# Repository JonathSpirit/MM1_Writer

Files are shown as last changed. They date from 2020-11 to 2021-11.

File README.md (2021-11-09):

# MM1_Writer

Copyright (C) 2021 Guillaume Guillet\
Licensed under CERN-OHL-W v2 or later

<table border="0px">
<tr>
<td>
This source describes Open Hardware and is licensed under the CERN-OHL-W v2 or later.
</td>
</tr>
<tr>
<td>
You may redistribute and modify this documentation and make products
using it under the terms of the CERN-OHL-W v2 (https:/cern.ch/cern-ohl).
This documentation is distributed WITHOUT ANY EXPRESS OR IMPLIED
WARRANTY, INCLUDING OF MERCHANTABILITY, SATISFACTORY QUALITY
AND FITNESS FOR A PARTICULAR PURPOSE. Please see the CERN-OHL-W v2
for applicable conditions.
</td>
</tr>
</table>

Made with [Kicad](https://kicad.org/)

## Description
This is a board helper for programming memory module that follow [MM1 standard](https://github.com/JonathSpirit/GComputer_standard).\
You can find the uc code here : [MM1_Writer_code](https://github.com/JonathSpirit/MM1_Writer_code).

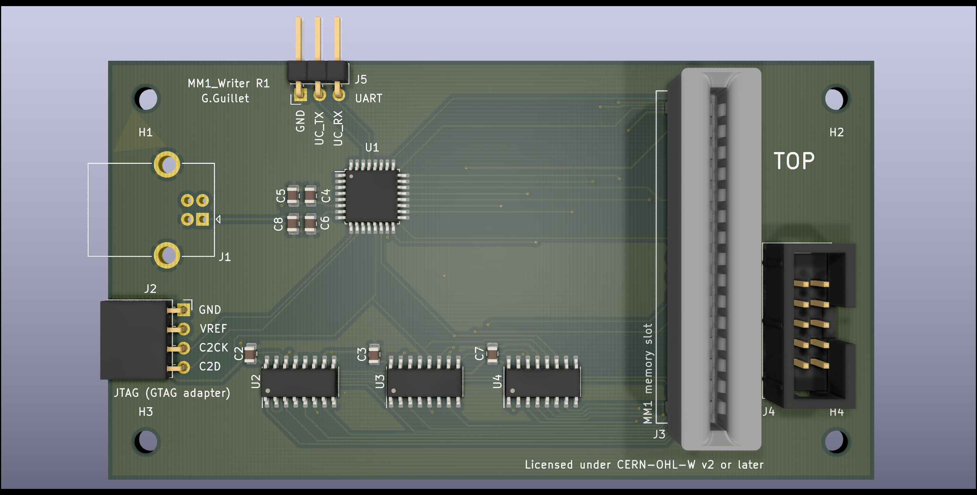
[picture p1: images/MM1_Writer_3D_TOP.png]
MM1_Writer_3D_TOP_image
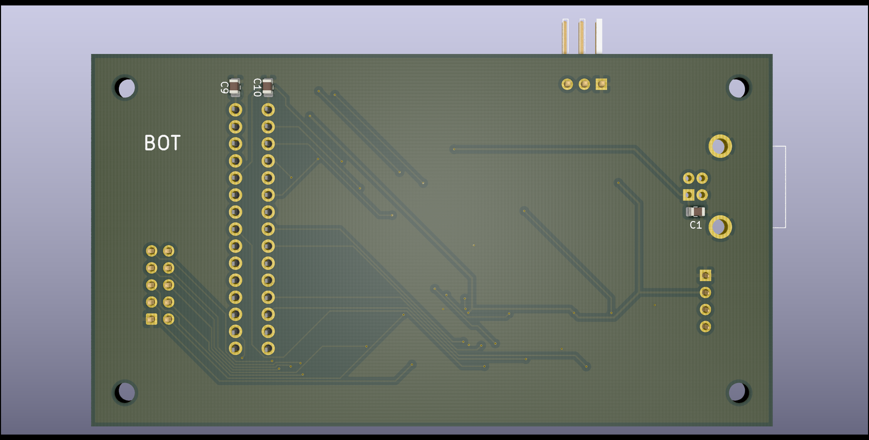
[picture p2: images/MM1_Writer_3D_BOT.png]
MM1_Writer_3D_BOT_image
 

## Stats





\
\
\


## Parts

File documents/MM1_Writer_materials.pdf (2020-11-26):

1

MM1_Writer_materials.fods

| MM1_Writer | R1
Author : Guillaume Guillet | Revision 1 | Licensed under CERN-OHL-W v2 or later
Type | Value | Q | References | Package | Manufacturer | Store | Store ID | Unit price* | Price
C | 10nF | 3 | C2, C3, C7 | C_0805_2012Metric | KEMET | Mouser | 80-C0805C103J5R | 0.092 | 0.276
| 1uF | 2 | C4, C6 | C_0805_2012Metric | KEMET | Mouser | 80-C0805C105K4RAC | 0.092 | 0.184
| 100nF | 5 | C1, C5, C8 to C10 | C_0805_2012Metric | KEMET | Mouser | 80-C0805C104M3R | 0.092 | 0.46
U | C8051F385-GQ | 1 | U1 | LQFP-32_7x7mm_P0.8mm | Silicon Labs | Mouser | 634-C8051F385-GQ | 2.52 | 2.52
| 74AHC595 | 3 | U2 to U4 | SOIC-16_3.9x9.9mm_P1.27mm | Texas Instruments | Mouser | 595-SN74AHC595DR | 0.485 | 1.455
J | Header10p | 1 | J4 | Header_10p_2.54 | Wurth Electronics | Mouser | 710-61201021621 | 0.411 | 0.411
| 5530843-2 | 1 | J3 | TE_5530843-2 | TE connectivity | Mouser | 571-5530843-2 | 2.33 | 2.33
| USB_B | 1 | J1 | USB_B_OST_USB-B1HSxx_Horizontal | Amphenol FCI | Mouser | 649-61729-0010BLF | 0.896 | 0.896
| PinSocket_1x04 | 1 | J2 | PinSocket_1x04_P2.54mm_Horizontal | Preci-dip | Mouser | 437-8018700420001101 | 0.585 | 0.585
| PinHeader_1x03 | 1 | J5 | PinHeader_1x03_P2.54mm_Horizontal | Molex | Mouser | 538-22-28-8033 | 0.247 | 0.247
- | PCB | 1 | - | - | G.Guillet | - | | | 0
Total price : | 9.364
*Depend of the quantity | Price is in CHF

# Project :

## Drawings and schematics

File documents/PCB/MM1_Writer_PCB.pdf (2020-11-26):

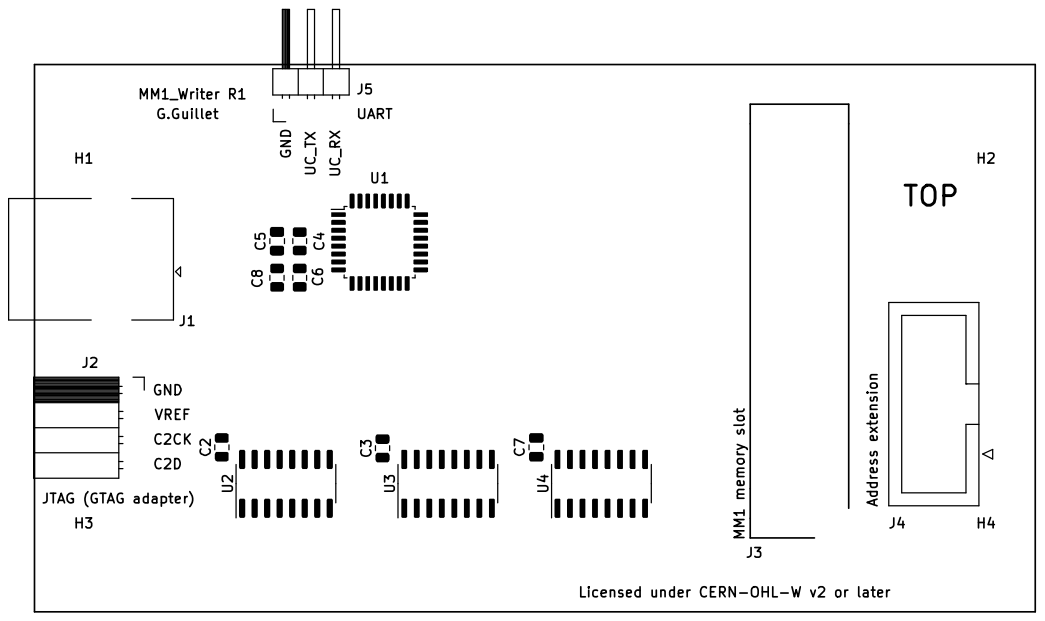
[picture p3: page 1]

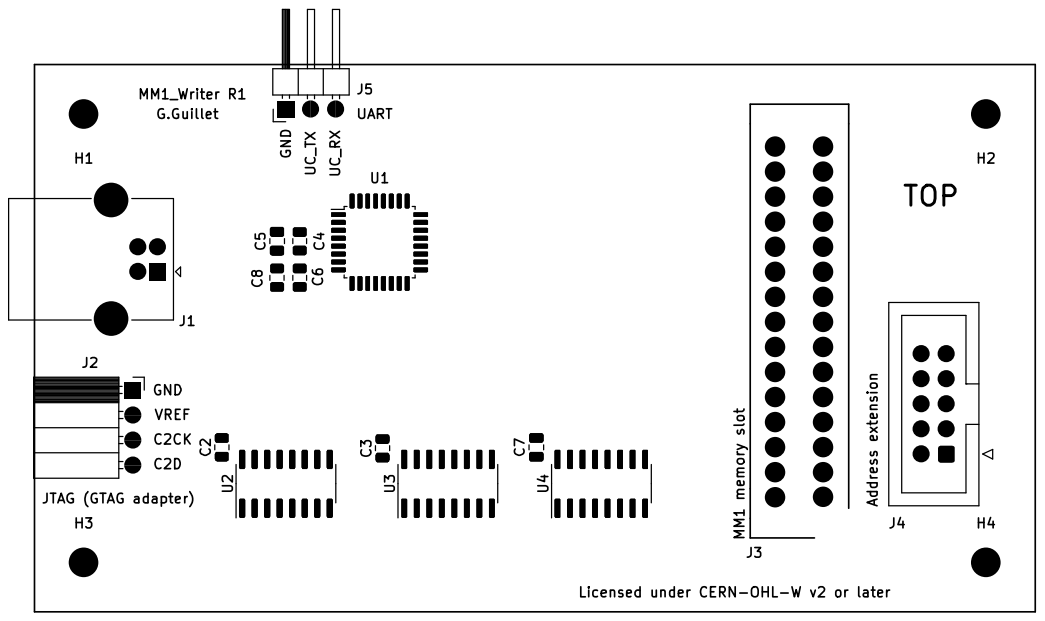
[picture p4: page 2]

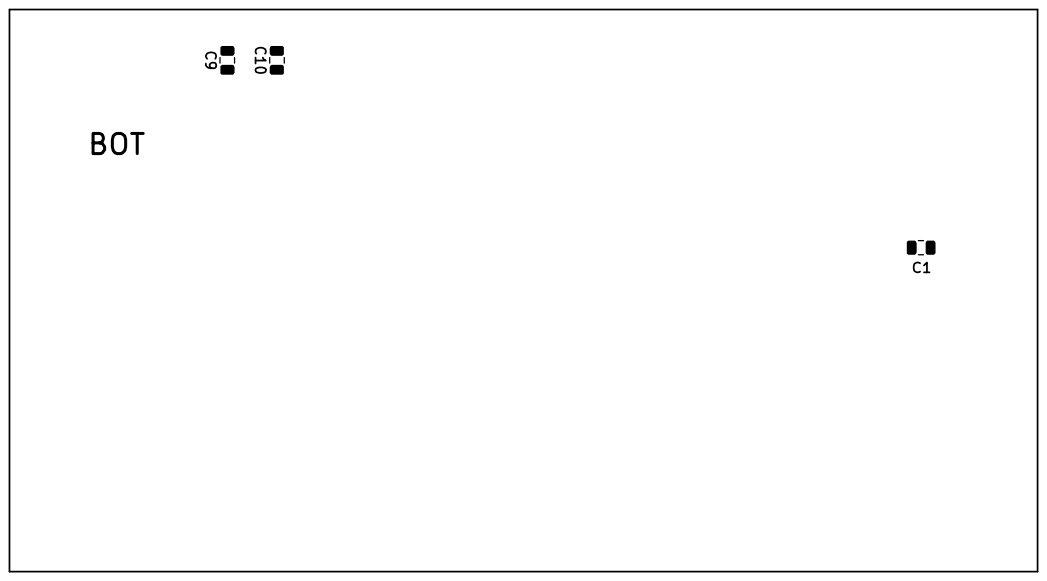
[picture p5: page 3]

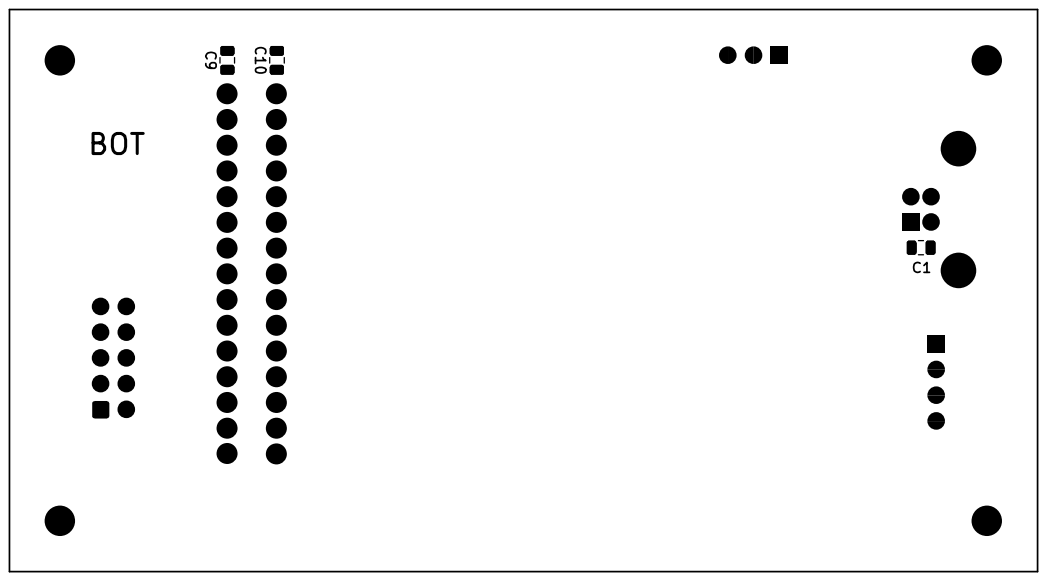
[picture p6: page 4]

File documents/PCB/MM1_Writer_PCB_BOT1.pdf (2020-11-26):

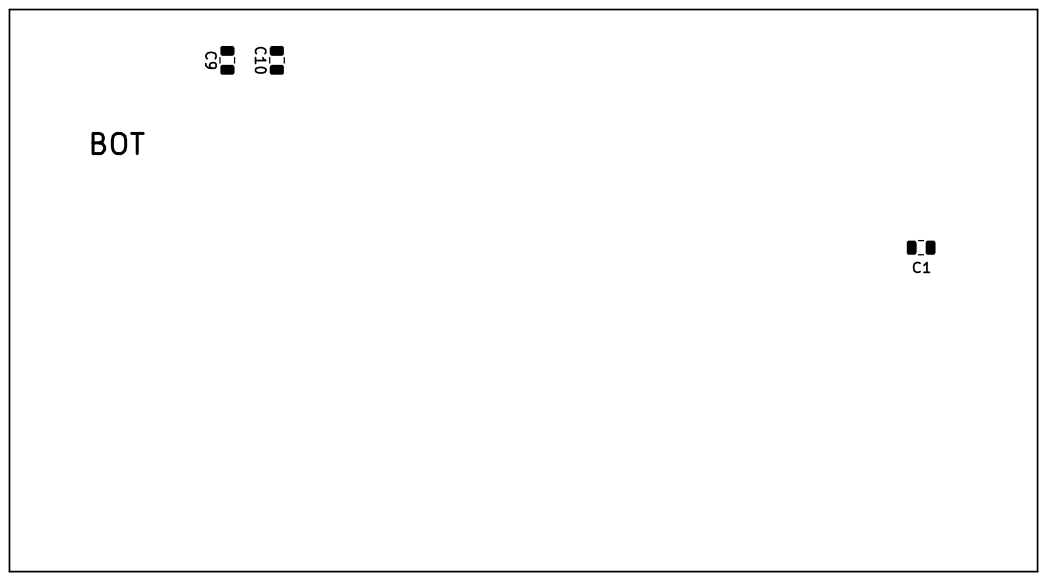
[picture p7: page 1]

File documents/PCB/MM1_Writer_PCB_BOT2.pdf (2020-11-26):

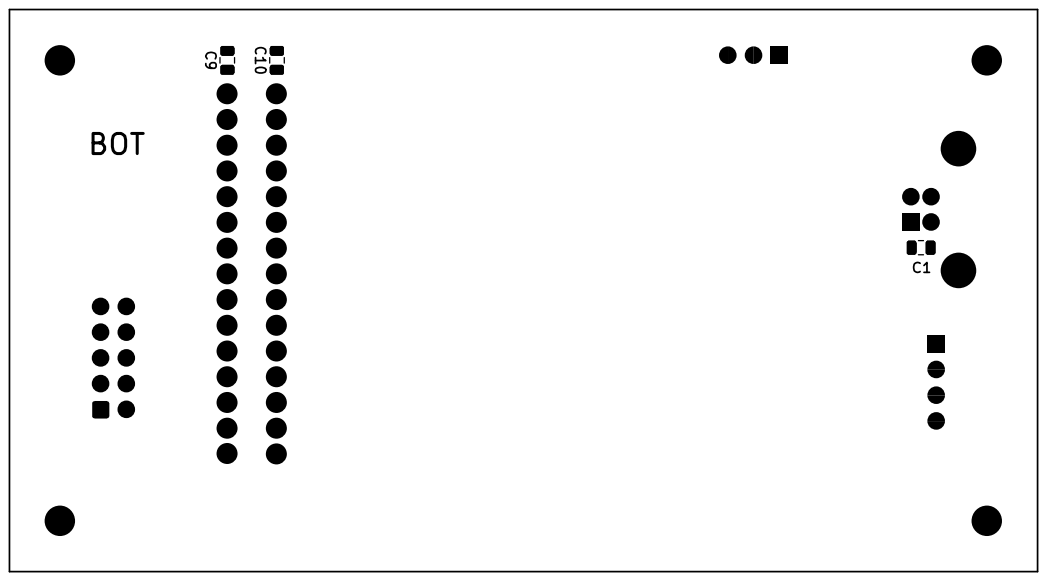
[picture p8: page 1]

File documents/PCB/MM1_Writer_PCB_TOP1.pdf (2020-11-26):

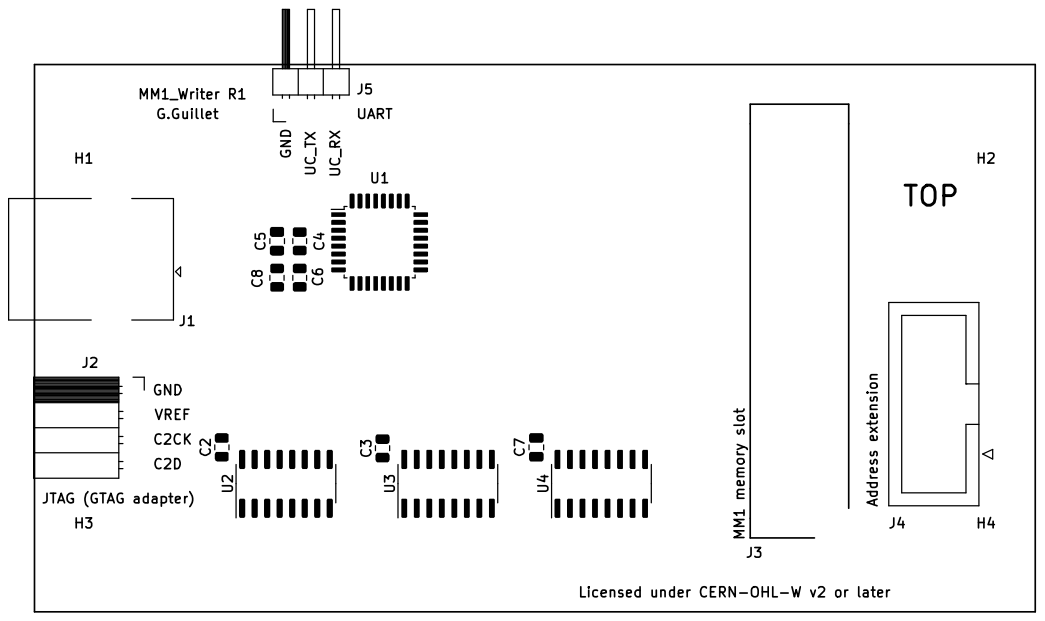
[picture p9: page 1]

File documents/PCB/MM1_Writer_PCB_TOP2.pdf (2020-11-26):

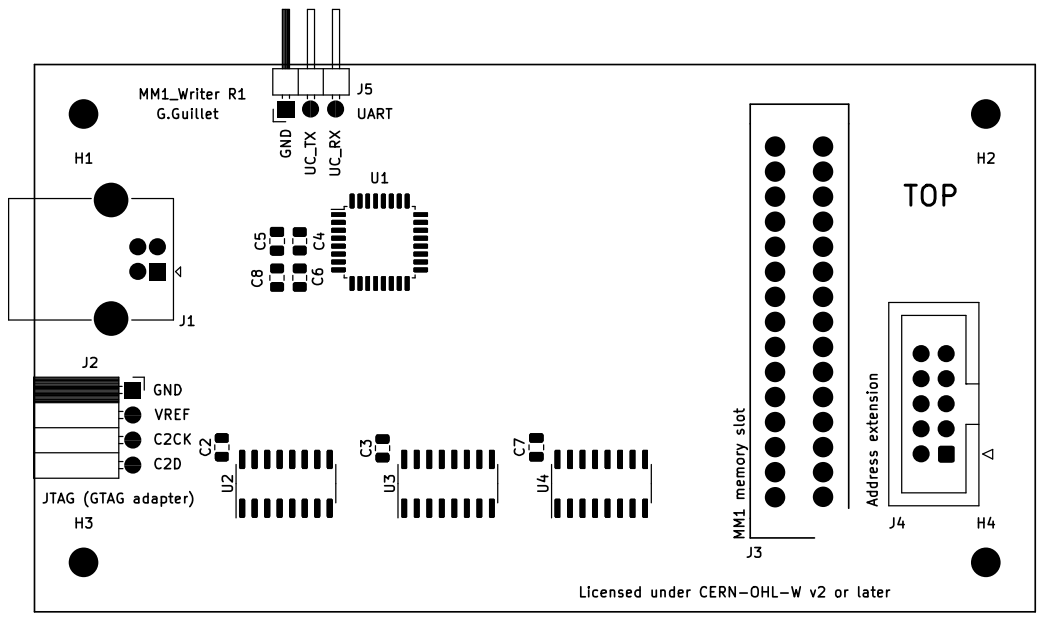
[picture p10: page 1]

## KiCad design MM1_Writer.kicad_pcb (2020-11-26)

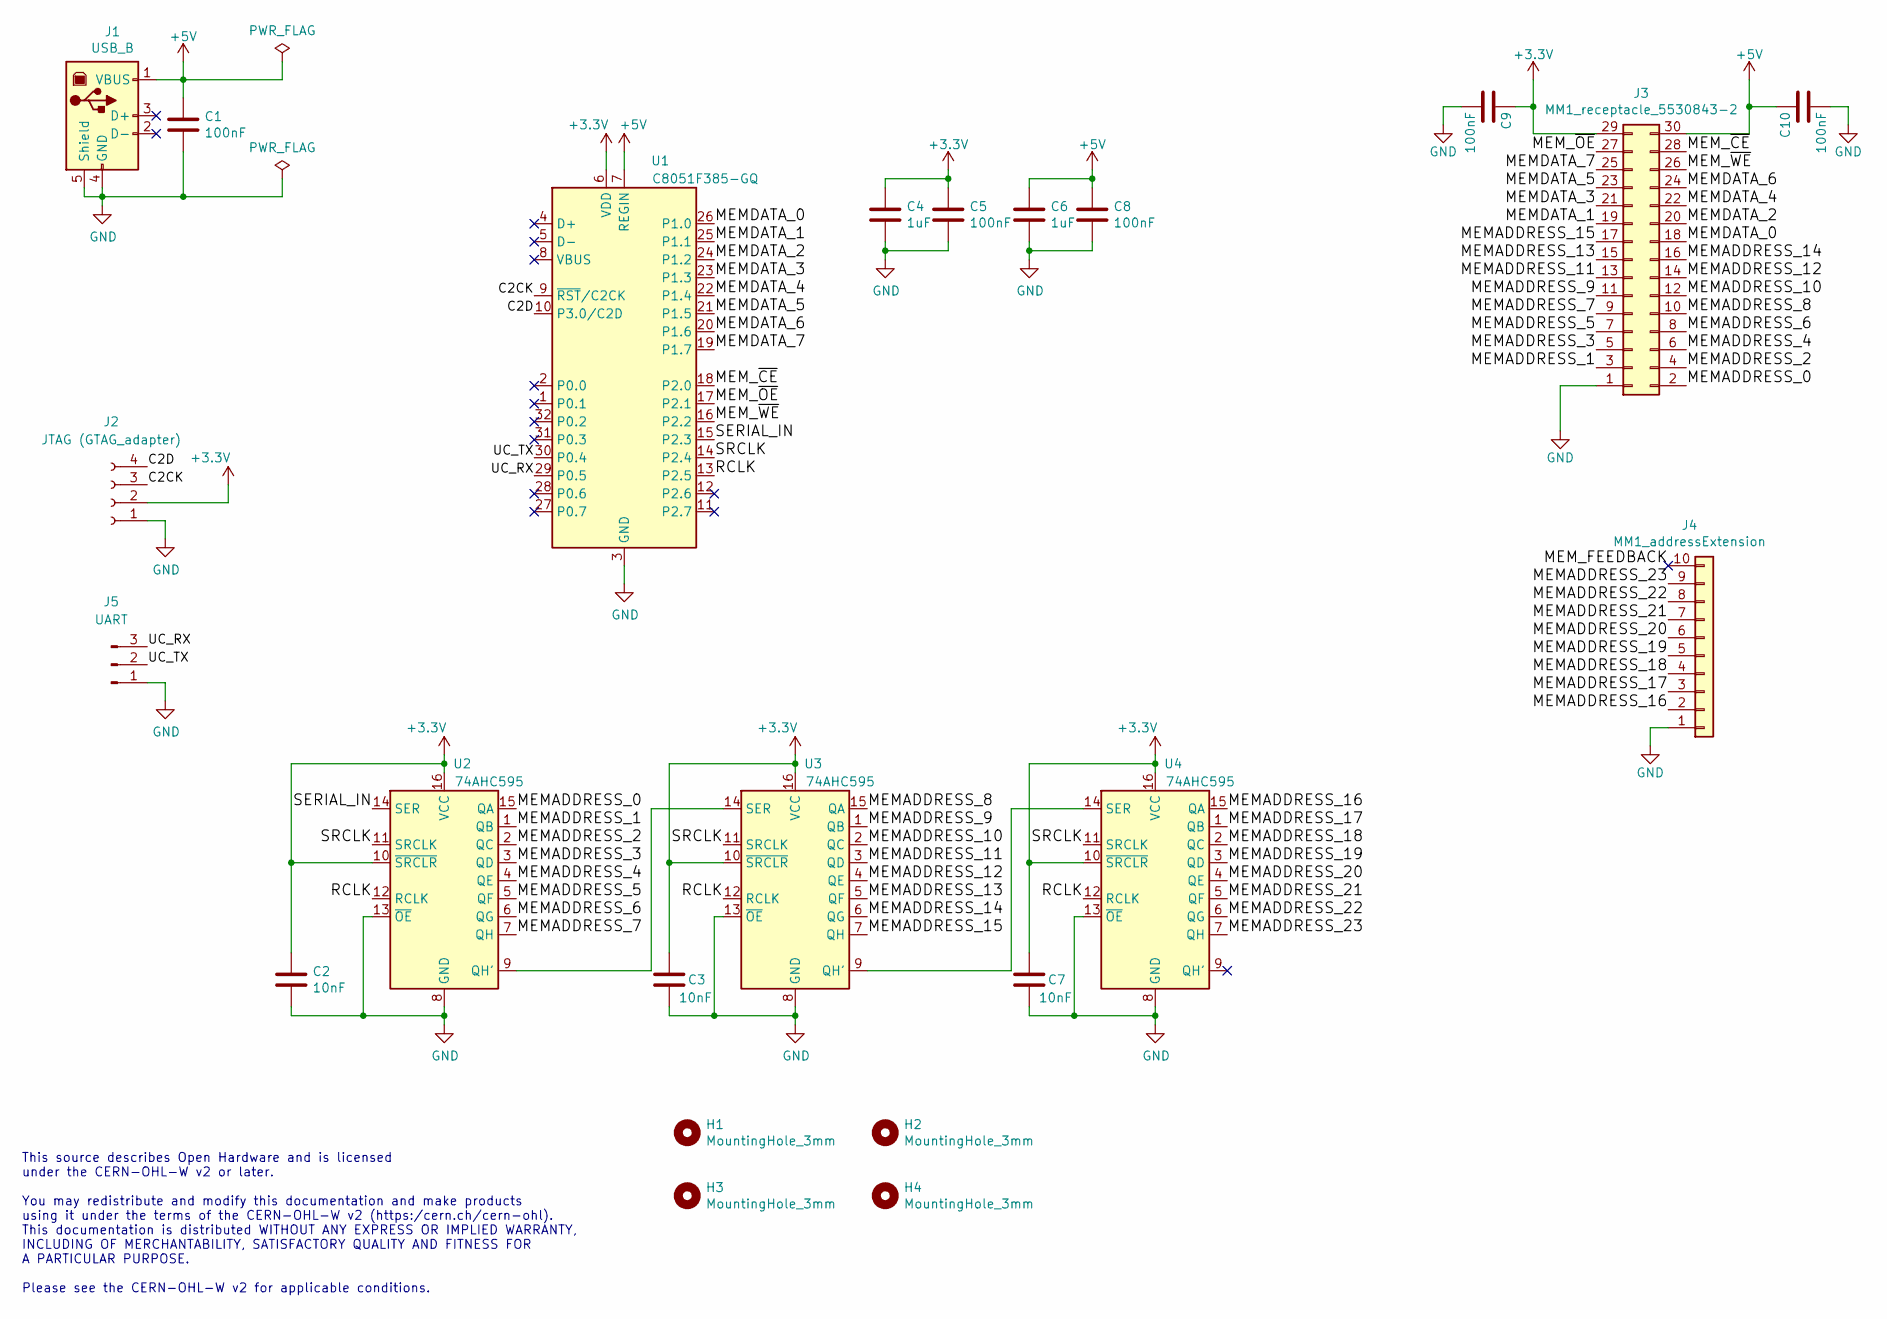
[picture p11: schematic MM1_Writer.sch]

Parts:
C1, C5, C8, C9, C10: 100nF; C_0805_2012Metric
C2, C3, C7: 10nF; C_0805_2012Metric
C4, C6: 1uF; C_0805_2012Metric
H1, H2, H3, H4: MountingHole_3mm
J1: USB_B; USB_B_OST_USB-B1HSxx_Horizontal
J2: JTAG (GTAG_adapter); PinSocket_1x04_P2.54mm_Horizontal
J3: MM1_receptacle_5530843-2; TE_5530843-2
J4: MM1_addressExtension; IDC-Header_2x05_P2.54mm_Vertical
J5: UART; PinHeader_1x03_P2.54mm_Horizontal
U1: C8051F385-GQ; LQFP-32_7x7mm_P0.8mm
U2, U3, U4: 74AHC595; SOIC-16_3.9x9.9mm_P1.27mm

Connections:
+3V3: C2.1, C3.1, C4.1, C5.1, C7.1, C9.1, J2.2, J3.29, U1.6 (VDD), U2.10 (~SRCLR), U2.16 (VCC), U3.10 (~SRCLR), U3.16 (VCC), U4.10 (~SRCLR), U4.16 (VCC)
+5V: C1.1, C6.1, C8.1, C10.1, J1.1 (VBUS), J3.30, U1.7 (REGIN)
/C2CK: J2.3, U1.9 (~RST~/C2CK)
/C2D: J2.4, U1.10 (P3.0/C2D)
/MEMADDRESS_0: J3.2, U2.15 (QA)
/MEMADDRESS_1: J3.3, U2.1 (QB)
/MEMADDRESS_2: J3.4, U2.2 (QC)
/MEMADDRESS_3: J3.5, U2.3 (QD)
/MEMADDRESS_4: J3.6, U2.4 (QE)
/MEMADDRESS_5: J3.7, U2.5 (QF)
/MEMADDRESS_6: J3.8, U2.6 (QG)
/MEMADDRESS_7: J3.9, U2.7 (QH)
/MEMADDRESS_8: J3.10, U3.15 (QA)
/MEMADDRESS_9: J3.11, U3.1 (QB)
/MEMADDRESS_10: J3.12, U3.2 (QC)
/MEMADDRESS_11: J3.13, U3.3 (QD)
/MEMADDRESS_12: J3.14, U3.4 (QE)
/MEMADDRESS_13: J3.15, U3.5 (QF)
/MEMADDRESS_14: J3.16, U3.6 (QG)
/MEMADDRESS_15: J3.17, U3.7 (QH)
/MEMADDRESS_16: J4.2, U4.15 (QA)
/MEMADDRESS_17: J4.3, U4.1 (QB)
/MEMADDRESS_18: J4.4, U4.2 (QC)
/MEMADDRESS_19: J4.5, U4.3 (QD)
/MEMADDRESS_20: J4.6, U4.4 (QE)
/MEMADDRESS_21: J4.7, U4.5 (QF)
/MEMADDRESS_22: J4.8, U4.6 (QG)
/MEMADDRESS_23: J4.9, U4.7 (QH)
/MEMDATA_0: J3.18, U1.26 (P1.0)
/MEMDATA_1: J3.19, U1.25 (P1.1)
/MEMDATA_2: J3.20, U1.24 (P1.2)
/MEMDATA_3: J3.21, U1.23 (P1.3)
/MEMDATA_4: J3.22, U1.22 (P1.4)
/MEMDATA_5: J3.23, U1.21 (P1.5)
/MEMDATA_6: J3.24, U1.20 (P1.6)
/MEMDATA_7: J3.25, U1.19 (P1.7)
/MEM_FEEDBACK: J4.10
/MEM_~CE: J3.28, U1.18 (P2.0)
/MEM_~OE: J3.27, U1.17 (P2.1)
/MEM_~WE: J3.26, U1.16 (P2.2)
/RCLK: U1.13 (P2.5), U2.12 (RCLK), U3.12 (RCLK), U4.12 (RCLK)
/SERIAL_IN: U1.15 (P2.3), U2.14 (SER)
/SRCLK: U1.14 (P2.4), U2.11 (SRCLK), U3.11 (SRCLK), U4.11 (SRCLK)
/UC_RX: J5.3, U1.29 (P0.5)
/UC_TX: J5.2, U1.30 (P0.4)
GND: C1.2, C2.2, C3.2, C4.2, C5.2, C6.2, C7.2, C8.2, C9.2, C10.2, J1.4 (GND), J1.5 (Shield), J2.1, J3.1, J4.1, J5.1, U1.3 (GND), U2.8 (GND), U2.13 (~OE), U3.8 (GND), U3.13 (~OE), U4.8 (GND), U4.13 (~OE)
unnamed: U2.9 (QH'), U3.14 (SER)
unnamed: U3.9 (QH'), U4.14 (SER)

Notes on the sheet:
This source describes Open Hardware and is licensed under the CERN-OHL-W v2 or later. You may redistribute and modify this documentation and make products using it under the terms of the CERN-OHL-W v2 (https:/cern.ch/cern-ohl). This documentation is distributed WITHOUT ANY EXPRESS OR IMPLIED WARRAN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

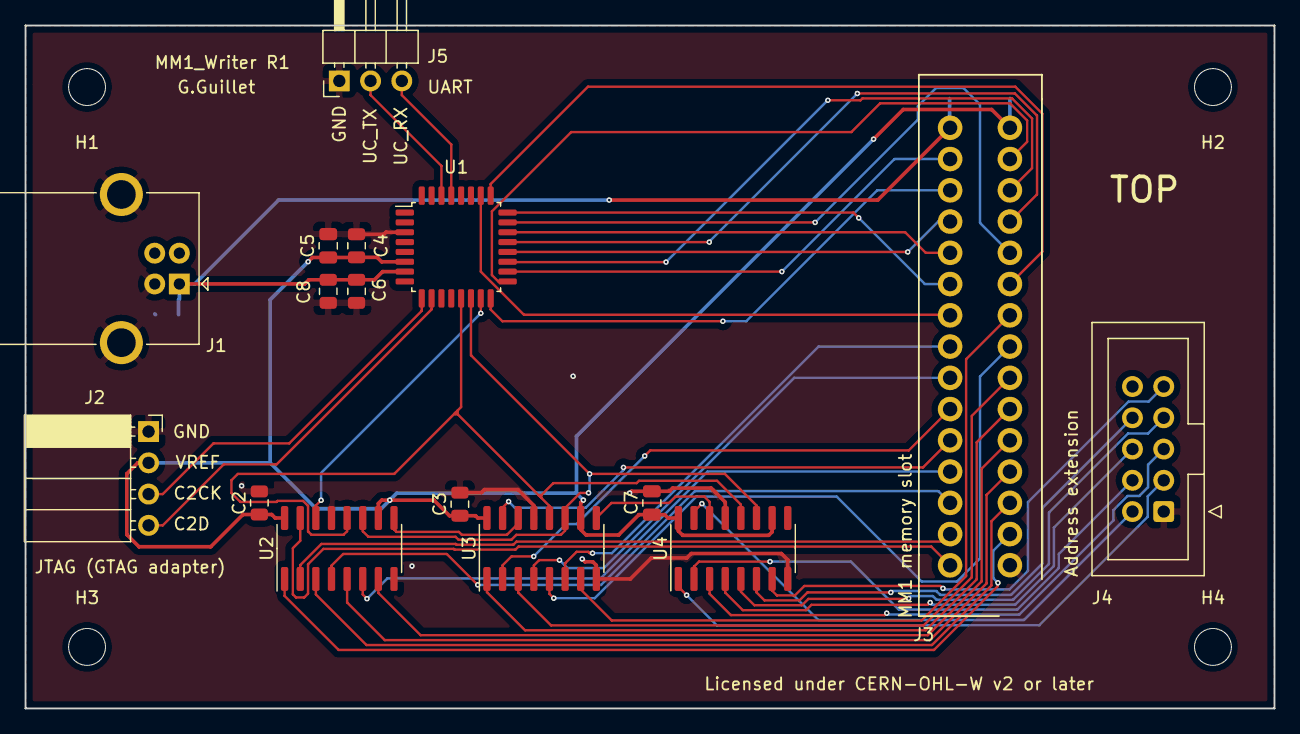
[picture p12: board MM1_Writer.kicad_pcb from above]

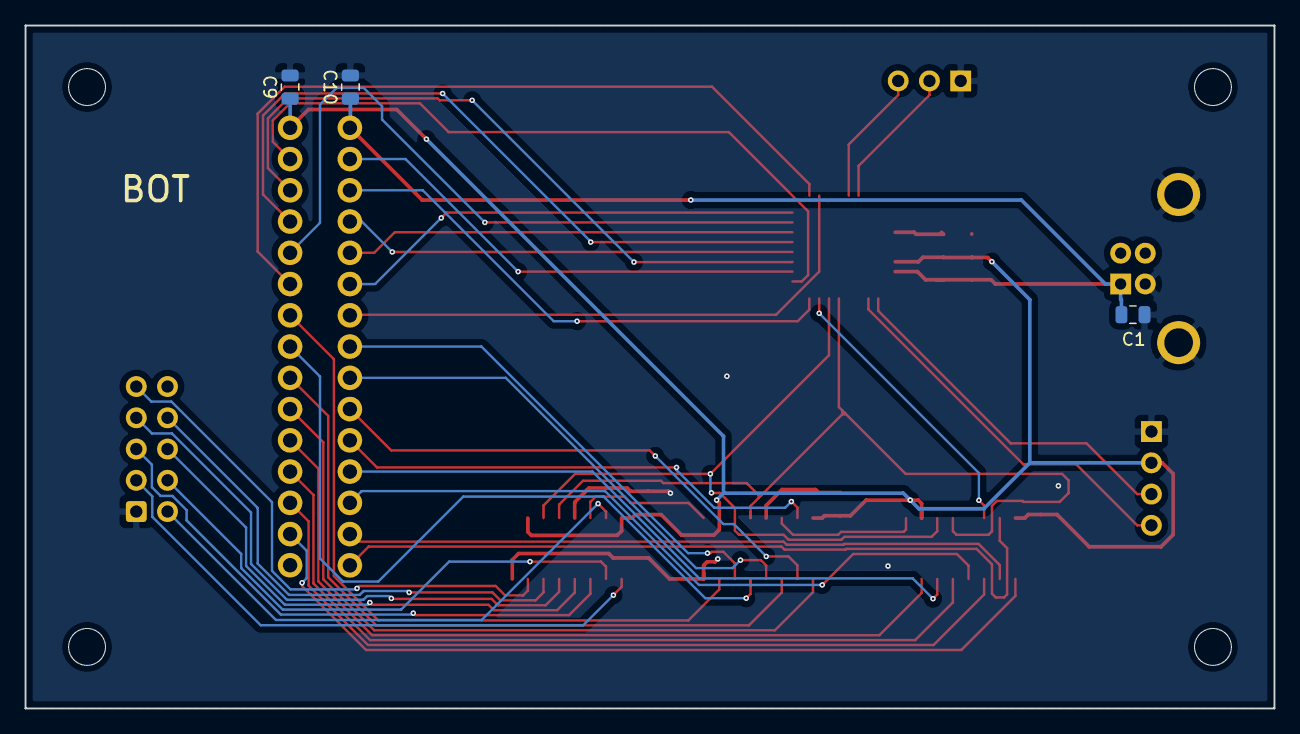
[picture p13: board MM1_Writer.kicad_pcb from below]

Board: 2 copper layers, 101.5 x 55.5 mm, 23 parts (3 on the bottom side), 47 nets.

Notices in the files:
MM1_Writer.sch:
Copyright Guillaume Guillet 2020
